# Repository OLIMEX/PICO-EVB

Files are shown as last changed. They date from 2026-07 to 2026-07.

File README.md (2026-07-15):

# PICO-EVB
Raspberry PICO/PICO-W evaluation board with optoisolated inputs 3.3-30VDC or 110-220VAC and Four Relays 15A/240VAC

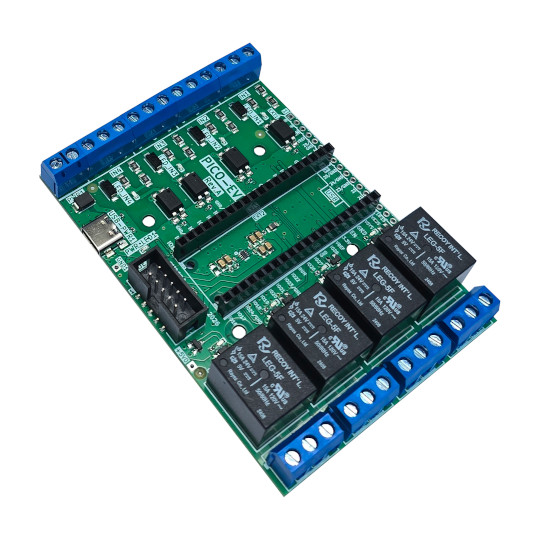
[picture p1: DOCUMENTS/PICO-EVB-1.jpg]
PICO-EVB-1


https://www.olimex.com/Products/RaspberryPi/PICO/PICO-EVB/

## Licensee
* Hardware is released under CERN Open Hardware Licence Version 2 - Strongly Reciprocal
* Software is released under MIT Licensee
* Documentation is released under CC BY-SA 4.0

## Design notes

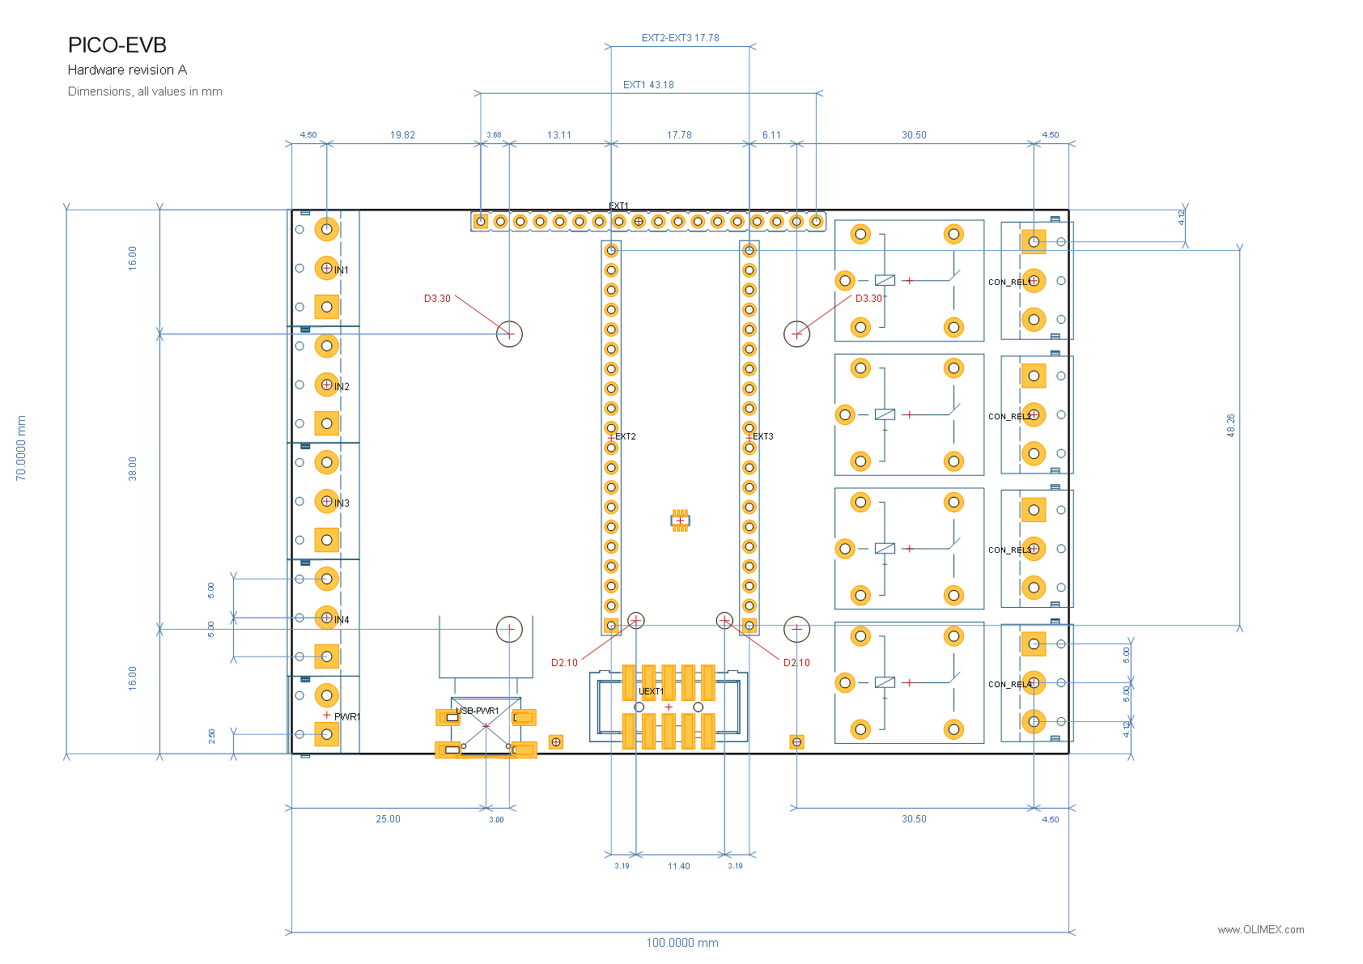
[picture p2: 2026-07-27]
DOCUMENTS/PICO-EVB-dimensions.png

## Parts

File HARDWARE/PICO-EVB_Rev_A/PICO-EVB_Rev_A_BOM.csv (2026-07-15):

Quantity | Value | Footprint | Reference
6 | 47uF/6.3V/20%/X5R/C0805 | C_0805_5MIL_DWS | C2, C3, C6, C8, C9, C10
3 | 100nF/10V/20%/X5R/C0402 | C_0402_5MIL_DWS | C4, C5, C7
8 | DG306-5.0-3P | TB3-DG306-5.0_3P | CON_REL1, CON_REL2, CON_REL3, CON_REL4, IN1, IN2, IN3, IN4
4 | 1N4148W(SOD-123) | SOD-123_1C-2A_KA | D1, D2, D7, D8
4 | 1N4007/SMA | SMA-KA | D3, D4, D5, D6
1 | SMBJ6.0A | DO214AA_1(K)-2(A) | D9
2 | PN1x20 | PN1x20 | EXT2, EXT3
1 | FB0805/600R/2A | L_0805_5MIL_DWS | L1
4 | LED/GREEN/0603 | LED_0603_KA | LED1, LED2, LED3, LED4
5 | LED/RED/0603 | LED_0603_KA | LED_IN1, LED_IN2, LED_IN3, LED_IN4, PWR_LED1
4 | PC817CS_CYPC817(C-TP2) | H11A817C_SMD(PC817X3NIP06)_FP | OPT1, OPT2, OPT3, OPT4
1 | DG306-5.0-2P | TB2-DG306-5.0_2P | PWR1
8 | 150k/R1206 | R_1206_5MIL_DWS | R1, R3, R5, R7, R11, R12, R13, R14
4 | 3.9k/R1206 | R_1206_5MIL_DWS | R2, R4, R6, R8
7 | 2.2k/R0402 | R_0402_5MIL_DWS | R9, R10, R17, R18, R23, R26, R27
1 | 24.9k/1%/R0402 | R_0402_5MIL_DWS | R15
1 | 6.81k/1%/R0402 | R_0402_5MIL_DWS | R16
4 | 47k/R0402 | R_0402_5MIL_DWS | R19, R20, R21, R22
2 | 5.1k/1%/R0402 | R_0402_5MIL_DWS | R24, R25
4 | RAS-0515 | Relay_RAS-05-15 | REL1, REL2, REL3, REL4
4 | LMUN2235LT1G(SOT-23) | SOT23 | T1, T2, T3, T4
1 | TPS2116 | SOT-5X3 | U1
1 | P-B-V-10-LF | GBH-254-SMT-10 | UEXT1
1 | USB-C-16P-F(A40-00119-A52-12) | USB2.0_TYPE-C(A40-00119-A52-12)_Paste | USB-PWR1

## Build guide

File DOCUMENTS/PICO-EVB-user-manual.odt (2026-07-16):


PICO-EVB

User Manual

Rev.1.0 July 2026 olimex.com

# Introduction to PICO-EVB

PICO-EVB (https://www.olimex.com/Products/RaspberryPi/PICO/PICO-EVB/) is evaluation board which can be used with Raspberry Pi PICO, PICO-W, PICO2 and PICO2-W. It also can work with Olimex RP2040-PICO30.

PICO-EVB (https://www.olimex.com/Products/RaspberryPi/PICO/PICO-EVB/) turns PICO into PLC and home automation device as it can drive high voltage loads with relays, and can sense via optoisolated inputs 3.3-30VDC or directly 110-220VAC signals.

PICO-EVB (https://www.olimex.com/Products/RaspberryPi/PICO/PICO-EVB/) have this features:

- 40 pin DIL connector for PICO modules
- USB-C power supply connector which allow more current to be used by the board
- Four 15A/240VAC relays controlled by the PICO
- UEXT connector
- Four opto-isolated inputs which can work either with 3.3-30VDC or 110-220VAC
- Power supply can be feed to screw connector terminal for more robust connection
- All components are industrial grade -45+85C
- Dimensions 100x70 mm

+ Important notice: The Relays and high voltage inputs should be used with care.

Each input have three connections: one common, one for +3.3-30VDC signals and one for 110/220VAC signals. If you want to drive the inputs with microcontroller feed 0 and +3.3V. If you want to drive the input with high voltage use live and neutral to connect. DO NOT CONNECT low voltage and high voltage to SAME input at the same time!

## Order codes for PICO-EVB and accessories:

PICO-EVB (https://www.olimex.com/Products/RaspberryPi/PICO/PICO-EVB/) industrial grade PICO evaluation board

USB-CABLE-A-TO-C-1M (https://www.olimex.com/Products/Components/Cables/USB/USB-CABLE-A-TO-C-1M/) USB-C quality cable for data and power

RP2040-PICO-HDR (https://www.olimex.com/Products/RaspberryPi/PICO/RP2040-PICO-HDR/) PICO with soldered headers

RP2040-PICO-W-HDR (https://www.olimex.com/Products/RaspberryPi/PICO/RP2040-PICO-W-HDR/) PICO-W with soldered headers

RP2350-PICO2-HDR (https://www.olimex.com/Products/RaspberryPi/PICO/RP2350-PICO2-HDR/) PICO2 with soldered headers

RP2350-PICO2-W-HDR (https://www.olimex.com/Products/RaspberryPi/PICO/RP2350-PICO2-W-HDR/) PICO2-W with soldered headers

# HARDWARE

## PICO-EVB layout:

PICO

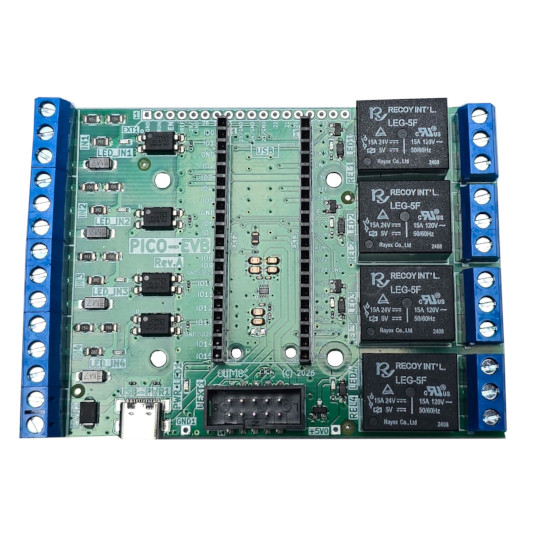
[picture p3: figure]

RELAY1

RELAY2

RELAY3

RELAY4

UEXT

GPIO connector

Input1

Input2

Input3

Input4

+5V PWR

USB-C

Relay staus LED

Power LED

Input status LED

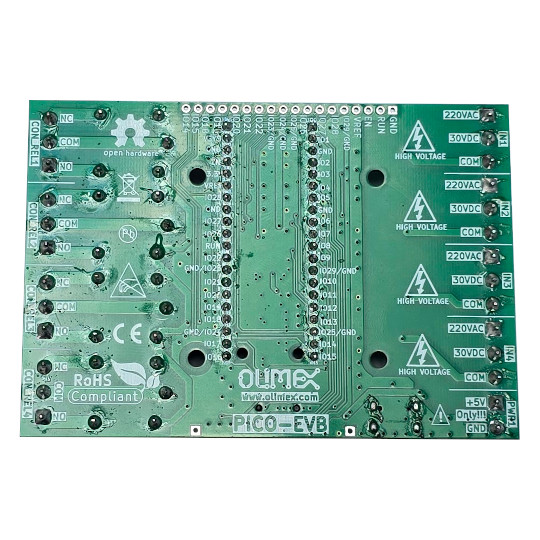
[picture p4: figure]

## PICO-EVB inputs:

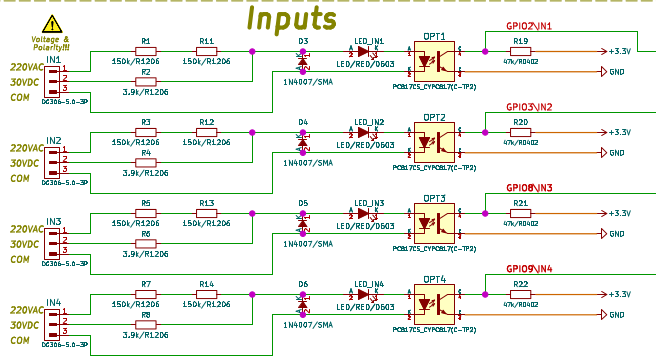
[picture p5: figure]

## PICO-EVB Relays:

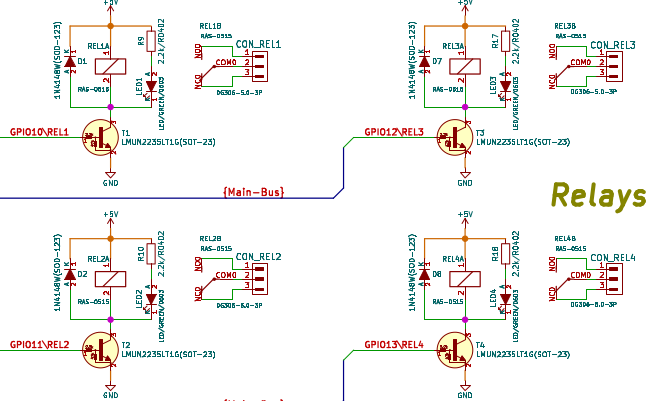
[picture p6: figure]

POWER SUPPLY:

PICO-EVB (https://www.olimex.com/Products/RaspberryPi/PICO/PICO-EVB/) can be powered by: USB-C connector, Terminal Block connector, PICO USB connector

You can connect any of them or all at the same time and it will be safe.

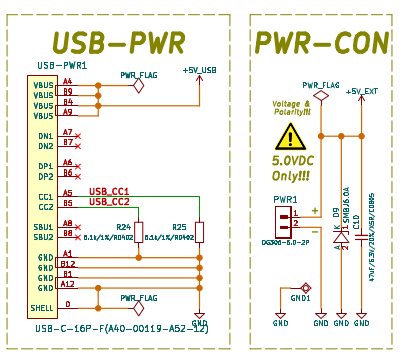
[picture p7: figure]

There is priority circuit if you connect together USB-C and Termianl block external power, the priority will be USB-C.

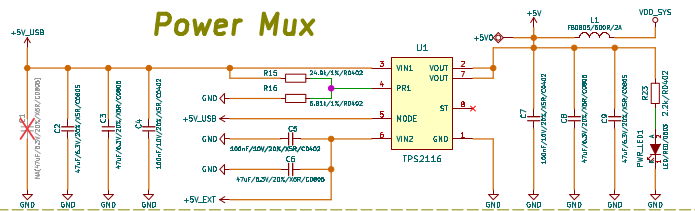
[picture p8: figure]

## PICO-EVB schematics:

PICO-EVB (https://www.olimex.com/Products/RaspberryPi/PICO/PICO-EVB/) latest schematic is on GitHub (https://github.com/OLIMEX/PICO-EVB)

## UEXT connector:

UEXT connector stands for Universal EXTension connector and contain +3.3V, GND, I2C, SPI, UART signals.

UEXT connector can be in different shapes.

The original UEXT connector is 0.1” 2.54mm step boxed plastic connector. All signals are with 3.3V levels.

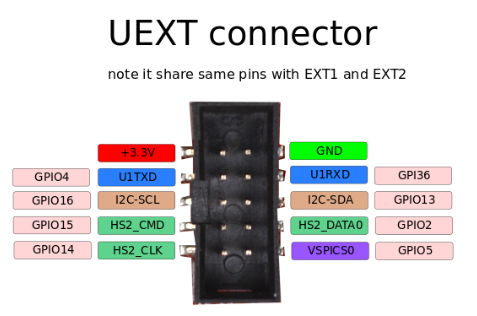
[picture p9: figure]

As the boards become smaller and smaller some smaller packages were introduced too beside the original UEXT connector

- mUEXT is 1.27 mm step boxed header connector which is with same layout as UEXT

- pUEXT is 1.0 mm single row connector (this is the connector used in RP2040-PICO30)

Olimex has developed number of MODULES (https://www.olimex.com/Products/Modules/) with this connector. There are temperature, humidity, pressure, magnetic field, light sensors. Modules with LCDs, LED matrix, Relays, Bluetooth, Zigbee, WiFi, GSM, GPS, RFID, RTC, EKG, sensors and etc.

# SOFTWARE:

PICO-EVB (https://www.olimex.com/Products/RaspberryPi/PICO/PICO-EVB/) repository have these software:

- Arduino-demo (https://github.com/OLIMEX/PICO-EVB/tree/main/SOFTWARE/Arduino-demo)
- ESPHome (https://github.com/OLIMEX/PICO-EVB/tree/main/SOFTWARE/ESPHome)
- MicroPython-demo (https://github.com/OLIMEX/PICO-EVB/tree/main/SOFTWARE/MicroPython-demo)
- MicroPython-server (https://github.com/OLIMEX/PICO-EVB/tree/main/SOFTWARE/MicroPython-server)

# Revision History

Revision 1.0 July 2026

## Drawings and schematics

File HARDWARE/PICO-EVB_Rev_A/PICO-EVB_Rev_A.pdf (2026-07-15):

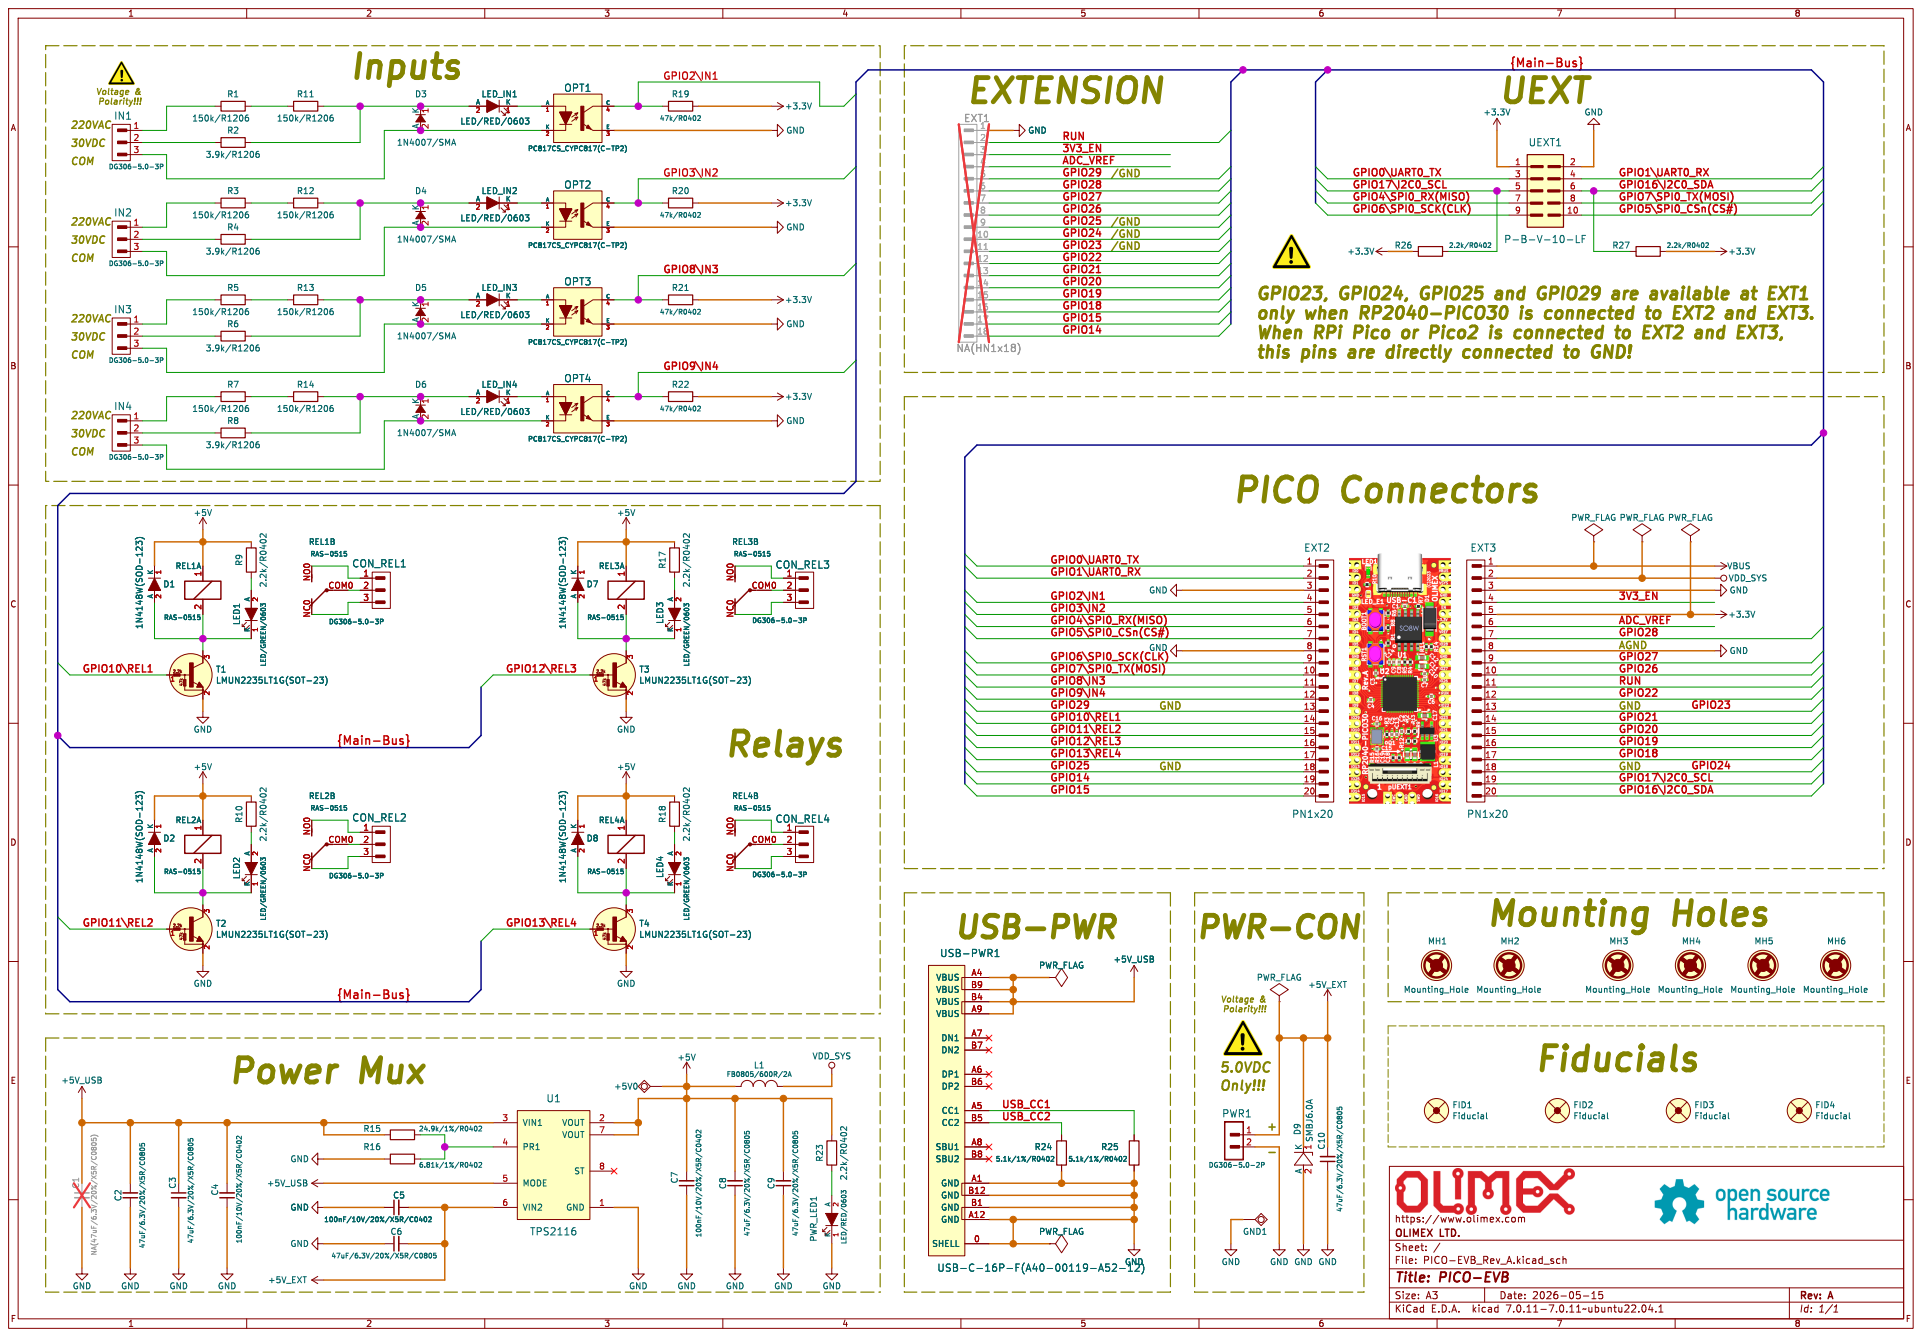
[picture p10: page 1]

When RPi Pico or Pico2 is connected to EXT2 and EXT3,
this pins are directly connected to GND!

File: PICO-EVB_Rev_A.kicad_sch Sheet: / OLIMEX LTD. https://www.olimex.com

Id: 1/1 Title: PICO-EVB

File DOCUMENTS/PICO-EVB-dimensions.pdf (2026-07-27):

# PICO-EVB

## Hardware revision A

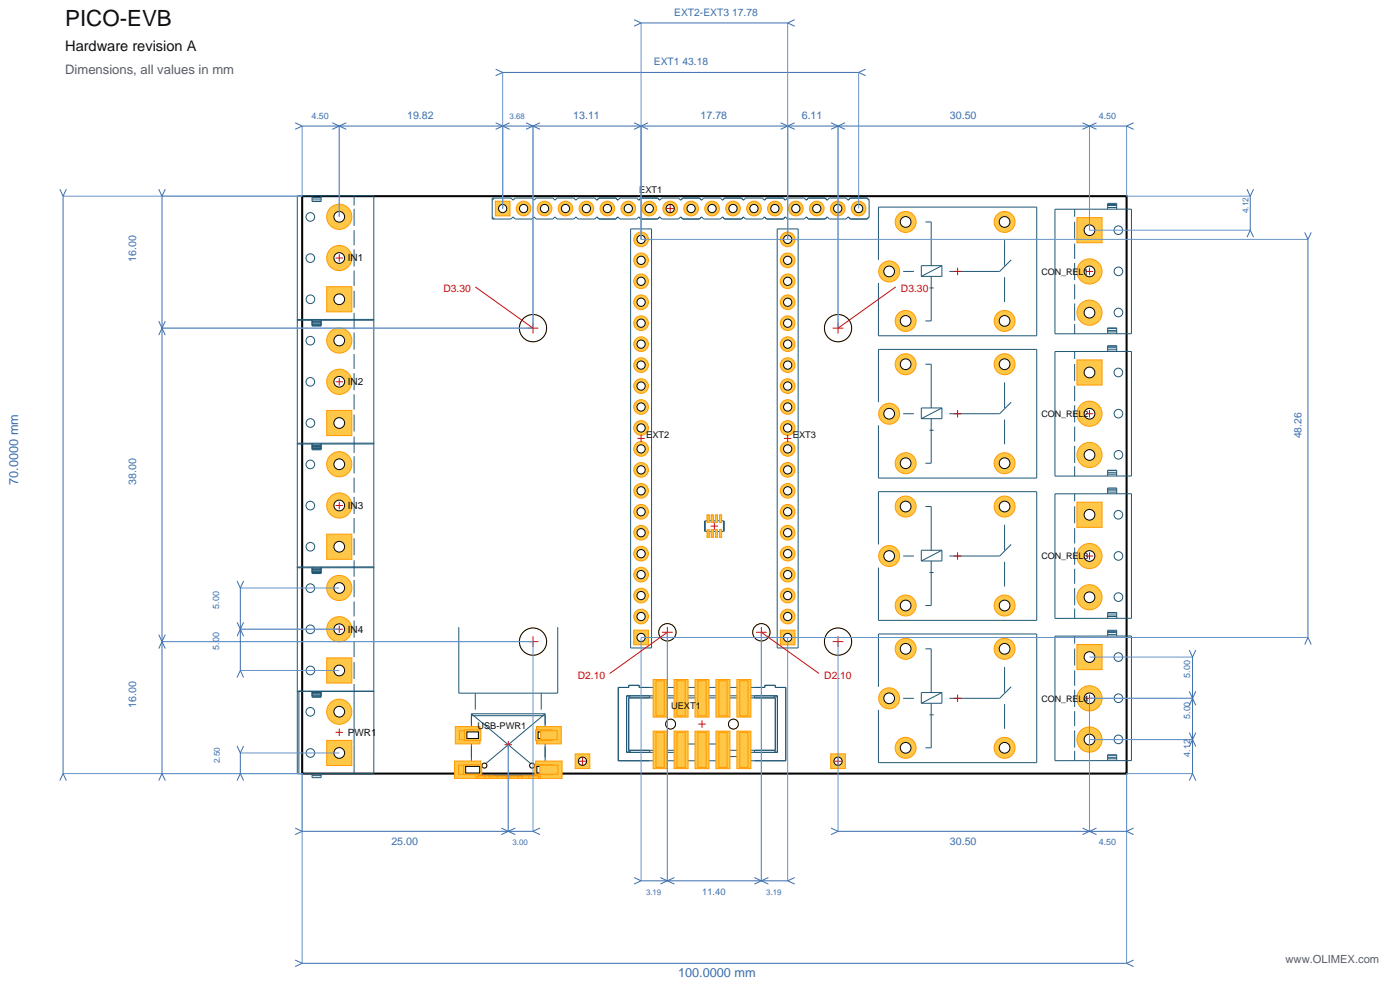
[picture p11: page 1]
CON_REL2; CON_REL4; EXT2; EXT1; UEXT1; CON_REL1; USB-PWR1 PWR1; EXT3; CON_REL3; EXT1 43.18; EXT2-EXT3 17.78

Dimensions, all values in mm

www.OLIMEX.com

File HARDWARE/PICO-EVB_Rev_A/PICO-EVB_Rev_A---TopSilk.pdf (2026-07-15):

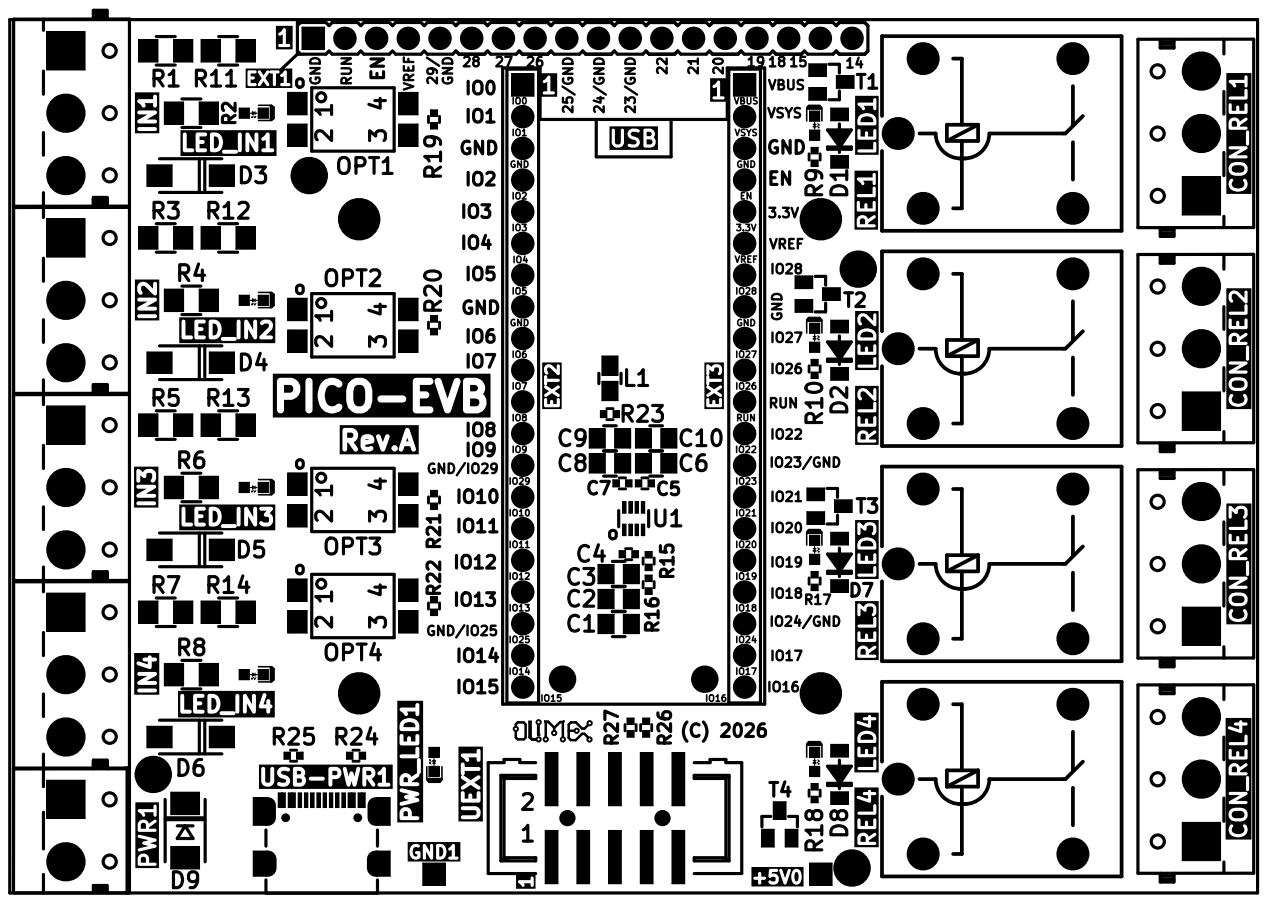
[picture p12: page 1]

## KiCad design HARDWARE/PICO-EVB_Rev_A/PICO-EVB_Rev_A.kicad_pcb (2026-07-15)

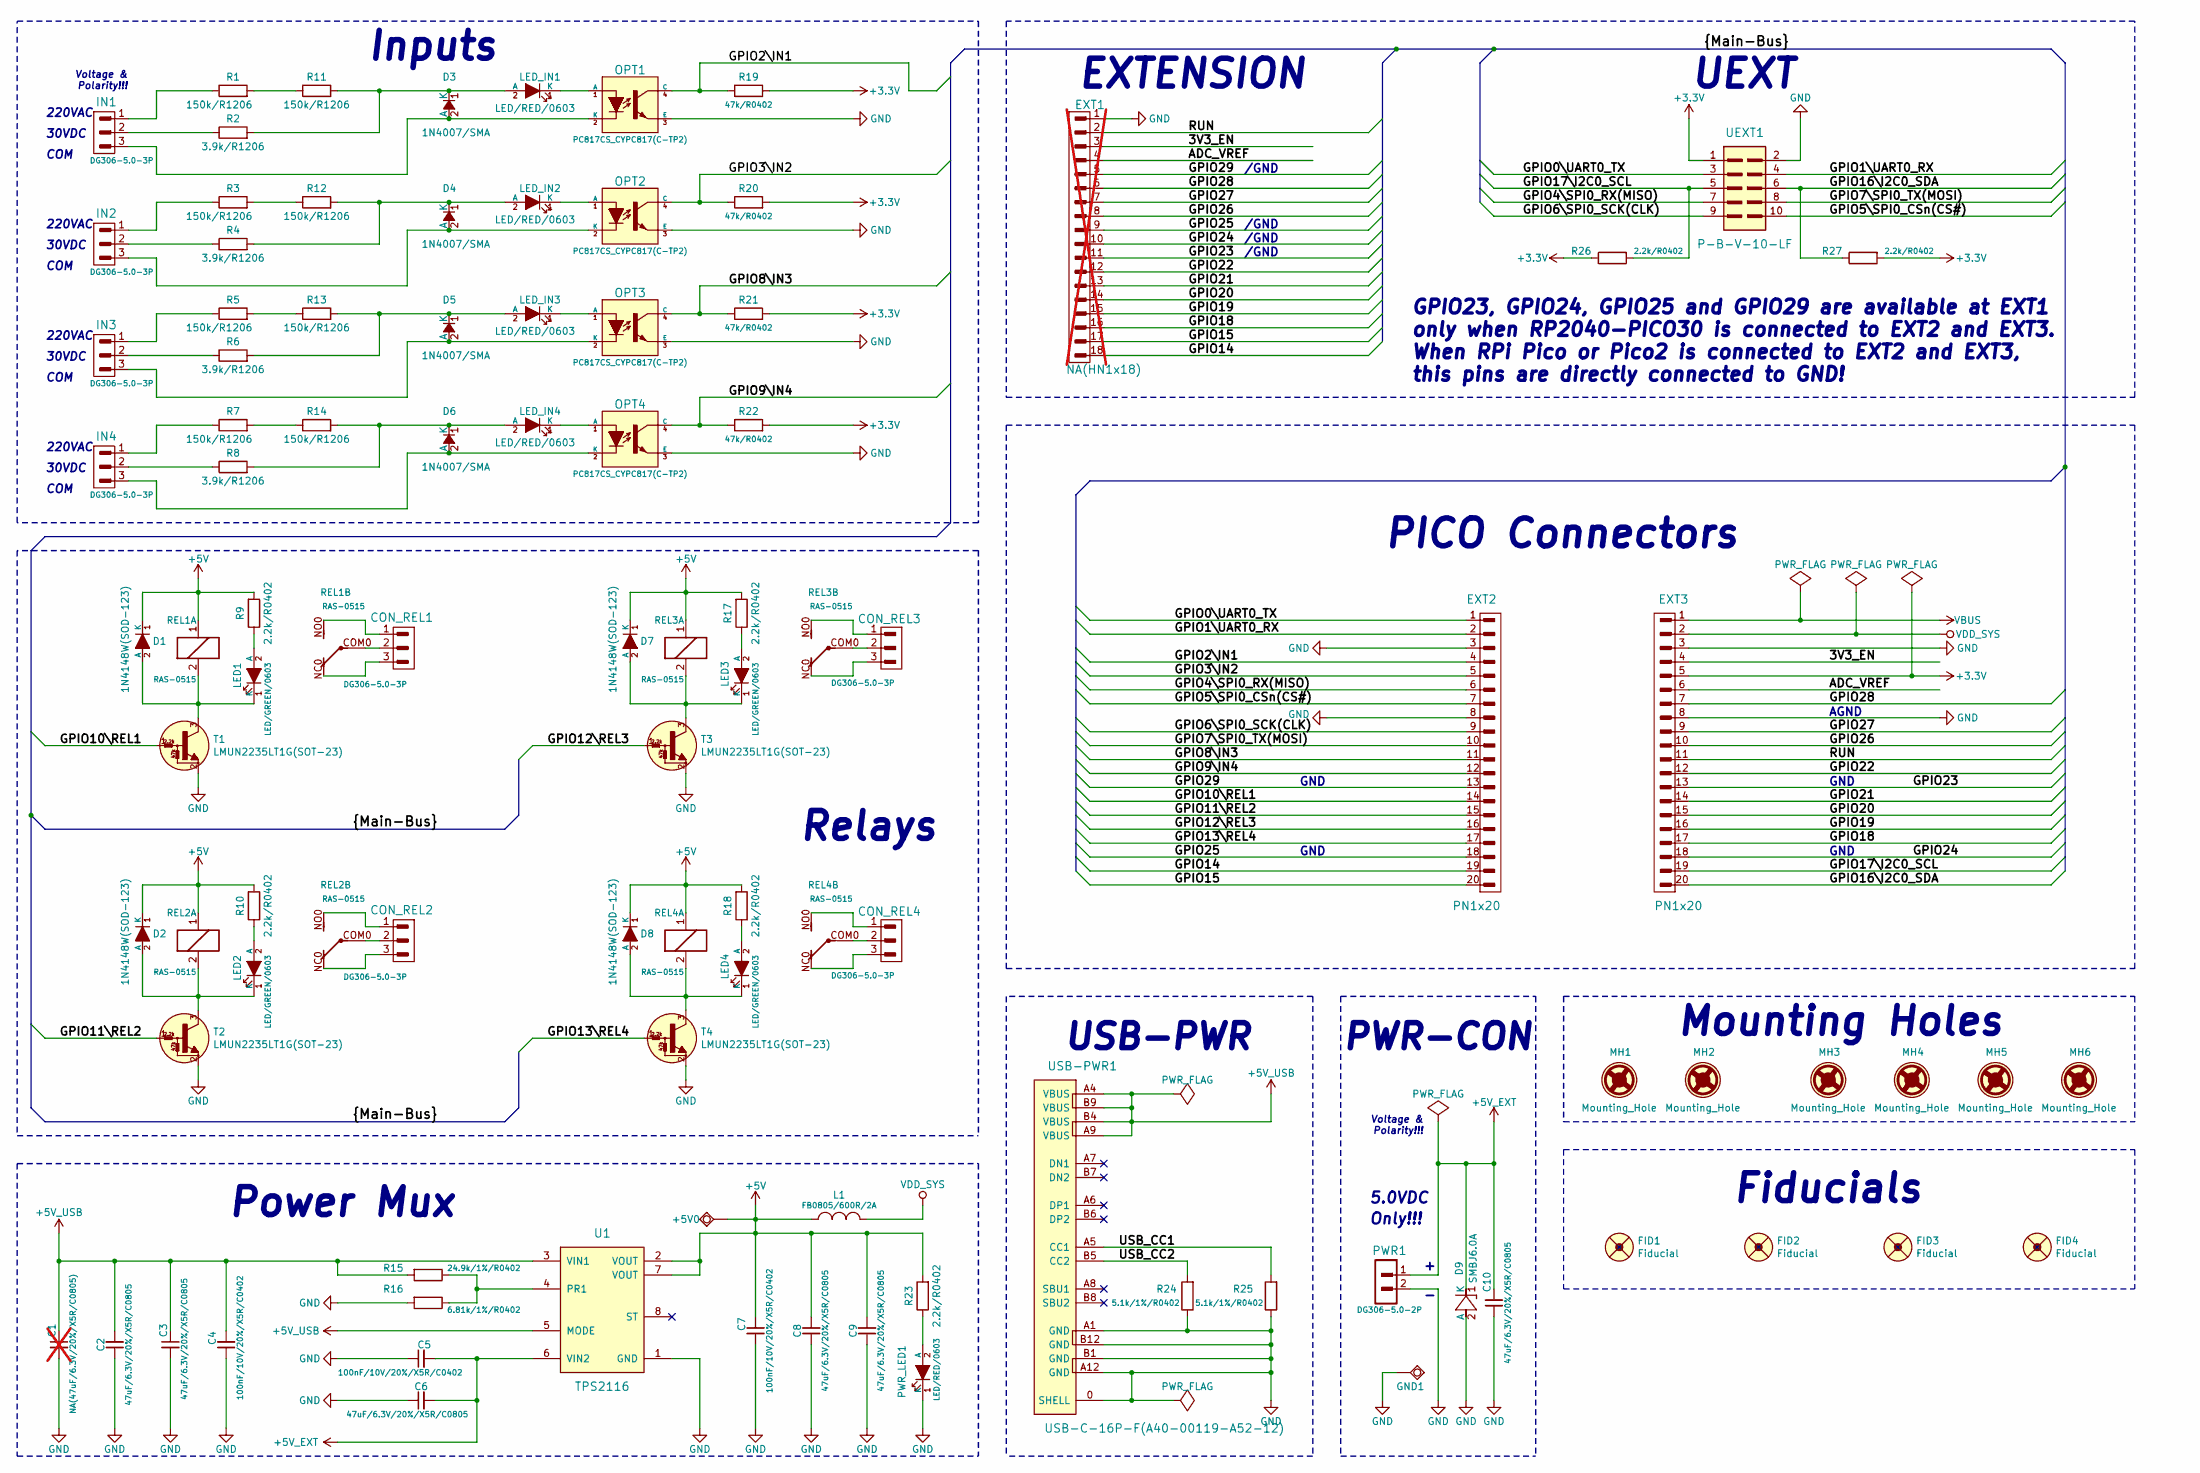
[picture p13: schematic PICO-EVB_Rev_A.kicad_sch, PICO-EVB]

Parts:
+5V0: TESTPAD; TEST_PAD40x70_SQUARE
C1: NA(47uF/6.3V/20%/X5R/C0805); C_0805_5MIL_DWS; not fitted
C2, C3, C6, C8, C9, C10: 47uF/6.3V/20%/X5R/C0805; C_0805_5MIL_DWS
C4, C5, C7: 100nF/10V/20%/X5R/C0402; C_0402_5MIL_DWS
CON_REL1, CON_REL2, CON_REL3, CON_REL4: DG306-5.0-3P; TB3-DG306-5.0_3P
D1, D2, D7, D8: 1N4148W(SOD-123); SOD-123_1C-2A_KA
D3, D4, D5, D6: 1N4007/SMA; SMA-KA
D9: SMBJ6.0A; DO214AA_1(K)-2(A)
EXT1: NA(HN1x18); HN1x18; not fitted
EXT2, EXT3: PN1x20
FID1, FID3: Fiducial; Fiducial1x3
FID2, FID4: Fiducial; Fiducial1x3_Paste
GND1: TESTPAD; TEST_PAD40x70_SQUARE
IN1, IN2, IN3, IN4: DG306-5.0-3P; TB3-DG306-5.0_3P
L1: FB0805/600R/2A; L_0805_5MIL_DWS
LED1, LED2, LED3, LED4: LED/GREEN/0603; LED_0603_KA
LED_IN1, LED_IN2, LED_IN3, LED_IN4: LED/RED/0603; LED_0603_KA
MH1, MH2: Mounting_Hole; Mounting_Hole_Drill-2.1mm_Clerance-4mm
MH3, MH4, MH5, MH6: Mounting_Hole; Mounting_Hole_Drill-3.3mm_Clerance-7mm
OPT1, OPT2, OPT3, OPT4: PC817CS_CYPC817(C-TP2); H11A817C_SMD(PC817X3NIP06)_FP
PWR1: DG306-5.0-2P; TB2-DG306-5.0_2P
PWR_LED1: LED/RED/0603; LED_0603_KA
R1, R3, R5, R7, R11, R12, R13, R14: 150k/R1206; R_1206_5MIL_DWS
R2, R4, R6, R8: 3.9k/R1206; R_1206_5MIL_DWS
R9, R10, R17, R18, R23, R26, R27: 2.2k/R0402; R_0402_5MIL_DWS
R15: 24.9k/1%/R0402; R_0402_5MIL_DWS
R16: 6.81k/1%/R0402; R_0402_5MIL_DWS
R19, R20, R21, R22: 47k/R0402; R_0402_5MIL_DWS
R24, R25: 5.1k/1%/R0402; R_0402_5MIL_DWS
REL1, REL2, REL3, REL4: RAS-0515; Relay_RAS-05-15
T1, T2, T3, T4: LMUN2235LT1G(SOT-23); SOT23
U1: TPS2116; SOT-5X3
UEXT1: P-B-V-10-LF; GBH-254-SMT-10
USB-PWR1: USB-C-16P-F(A40-00119-A52-12); USB2.0_TYPE-C(A40-00119-A52-12)_Paste

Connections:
+3.3V: EXT3.5, R19.2, R20.2, R21.2, R22.2, R26.1, R27.2, UEXT1.1
+5V: +5V0.1 (Pad), C7.2, C8.2, C9.2, D1.1 (K), D2.1 (K), D7.1 (K), D8.1 (K), L1.1, R9.2, R10.2, R17.2, R18.2, R23.2, REL1.1, REL2.1, REL3.1, REL4.1, U1.2 (VOUT), U1.7 (VOUT)
+5V_EXT: C5.2, C6.2, C10.2, D9.1 (K), PWR1.1, U1.6 (VIN2)
+5V_USB: C1.1, C2.2, C3.1, C4.2, R15.2, U1.3 (VIN1), U1.5 (MODE), USB-PWR1.A4 (VBUS), USB-PWR1.A9 (VBUS), USB-PWR1.B4 (VBUS), USB-PWR1.B9 (VBUS)
/3V3_EN: EXT1.3, EXT3.4
/ADC_VREF: EXT1.4, EXT3.6
/GPIO0\UART0_TX: EXT2.1, UEXT1.3
/GPIO1\UART0_RX: EXT2.2, UEXT1.4
/GPIO2\IN1: EXT2.4, OPT1.4 (C), R19.1
/GPIO3\IN2: EXT2.5, OPT2.4 (C), R20.1
/GPIO4\SPI0_RX(MISO): EXT2.6, UEXT1.7
/GPIO5\SPI0_CSn(CS#): EXT2.7, UEXT1.10
/GPIO6\SPI0_SCK(CLK): EXT2.9, UEXT1.9
/GPIO7\SPI0_TX(MOSI): EXT2.10, UEXT1.8
/GPIO8\IN3: EXT2.11, OPT3.4 (C), R21.1
/GPIO9\IN4: EXT2.12, OPT4.4 (C), R22.1
/GPIO10\REL1: EXT2.14, T1.1 (B)
/GPIO11\REL2: EXT2.15, T2.1 (B)
/GPIO12\REL3: EXT2.16, T3.1 (B)
/GPIO13\REL4: EXT2.17, T4.1 (B)
/GPIO14: EXT1.18, EXT2.19
/GPIO15: EXT1.17, EXT2.20
/GPIO16\I2C0_SDA: EXT3.20, R27.1, UEXT1.6
/GPIO17\I2C0_SCL: EXT3.19, R26.2, UEXT1.5
/GPIO18: EXT1.16, EXT3.17
/GPIO19: EXT1.15, EXT3.16
/GPIO20: EXT1.14, EXT3.15
/GPIO21: EXT1.13, EXT3.14
/GPIO22: EXT1.12, EXT3.12
/GPIO23: EXT1.11, EXT3.13
/GPIO24: EXT1.10, EXT3.18
/GPIO25: EXT1.9, EXT2.18
/GPIO26: EXT1.8, EXT3.10
/GPIO27: EXT1.7, EXT3.9
/GPIO28: EXT1.6, EXT3.7
/GPIO29: EXT1.5, EXT2.13
/RUN: EXT1.2, EXT3.11
/USB_CC1: R25.2, USB-PWR1.A5 (CC1)
/USB_CC2: R24.2, USB-PWR1.B5 (CC2)
GND: C1.2, C2.1, C3.2, C4.1, C5.1, C6.1, C7.1, C8.1, C9.1, C10.1, D9.2 (A), EXT1.1, EXT2.3, EXT2.8, EXT3.3, EXT3.8, GND1.1 (Pad), OPT1.3 (E), OPT2.3 (E), OPT3.3 (E), OPT4.3 (E), PWR1.2, PWR_LED1.1 (K), R16.2, R24.1, R25.1, T1.2 (E), T2.2 (E), T3.2 (E), T4.2 (E), U1.1 (GND), UEXT1.2, USB-PWR1.0 (SHELL), USB-PWR1.A1 (GND), USB-PWR1.A12 (GND), USB-PWR1.B1 (GND), USB-PWR1.B12 (GND)
unnamed: CON_REL1.1, REL1.NO0
unnamed: CON_REL1.2, REL1.COM0
unnamed: CON_REL1.3, REL1.NC0
unnamed: CON_REL2.1, REL2.NO0
unnamed: CON_REL2.2, REL2.COM0
unnamed: CON_REL2.3, REL2.NC0
unnamed: CON_REL3.1, REL3.NO0
unnamed: CON_REL3.2, REL3.COM0
unnamed: CON_REL3.3, REL3.NC0
unnamed: CON_REL4.1, REL4.NO0
unnamed: CON_REL4.2, REL4.COM0
unnamed: CON_REL4.3, REL4.NC0
unnamed: D1.2 (A), LED1.1 (K), REL1.2, T1.3 (C)
unnamed: D2.2 (A), LED2.1 (K), REL2.2, T2.3 (C)
unnamed: D3.2 (A), IN1.3, OPT1.2 (K)
unnamed: D3.1 (K), LED_IN1.2 (A), R2.2, R11.2
unnamed: D4.2 (A), IN2.3, OPT2.2 (K)
unnamed: D4.1 (K), LED_IN2.2 (A), R4.2, R12.2
unnamed: D5.2 (A), IN3.3, OPT3.2 (K)
unnamed: D5.1 (K), LED_IN3.2 (A), R6.2, R13.2
unnamed: D6.2 (A), IN4.3, OPT4.2 (K)
unnamed: D6.1 (K), LED_IN4.2 (A), R8.2, R14.2
unnamed: D7.2 (A), LED3.1 (K), REL3.2, T3.3 (C)
unnamed: D8.2 (A), LED4.1 (K), REL4.2, T4.3 (C)
unnamed: IN1.1, R1.1
unnamed: IN1.2, R2.1
unnamed: IN2.1, R3.1
unnamed: IN2.2, R4.1
unnamed: IN3.1, R5.1
unnamed: IN3.2, R6.1
unnamed: IN4.1, R7.1
unnamed: IN4.2, R8.1
unnamed: LED1.2 (A), R9.1
unnamed: LED2.2 (A), R10.1
unnamed: LED3.2 (A), R17.1
unnamed: LED4.2 (A), R18.1
unnamed: LED_IN1.1 (K), OPT1.1 (A)
unnamed: LED_IN2.1 (K), OPT2.1 (A)
unnamed: LED_IN3.1 (K), OPT3.1 (A)
unnamed: LED_IN4.1 (K), OPT4.1 (A)
unnamed: PWR_LED1.2 (A), R23.1
unnamed: R1.2, R11.1
unnamed: R3.2, R12.1
unnamed: R5.2, R13.1
unnamed: R7.2, R14.1
unnamed: R15.1, R16.1, U1.4 (PR1)
VBUS: EXT3.1
VDD_SYS: EXT3.2, L1.2

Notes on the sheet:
30VDC
PWR-CON
220VAC
/GND
AGND
Mounting Holes
USB-PWR
Fiducials
COM
Voltage & Polarity!!!
EXTENSION
GPIO23, GPIO24, GPIO25 and GPIO29 are available at EXT1 only when RP2040-PICO30 is connected to EXT2 and EXT3. When RPi Pico or Pico2 is connected to EXT2 and EXT3, this pins are directly connected to GND!
5.0VDC
Relays
Power Mux
UEXT
GND
Inputs
PICO Connectors
Only!!!

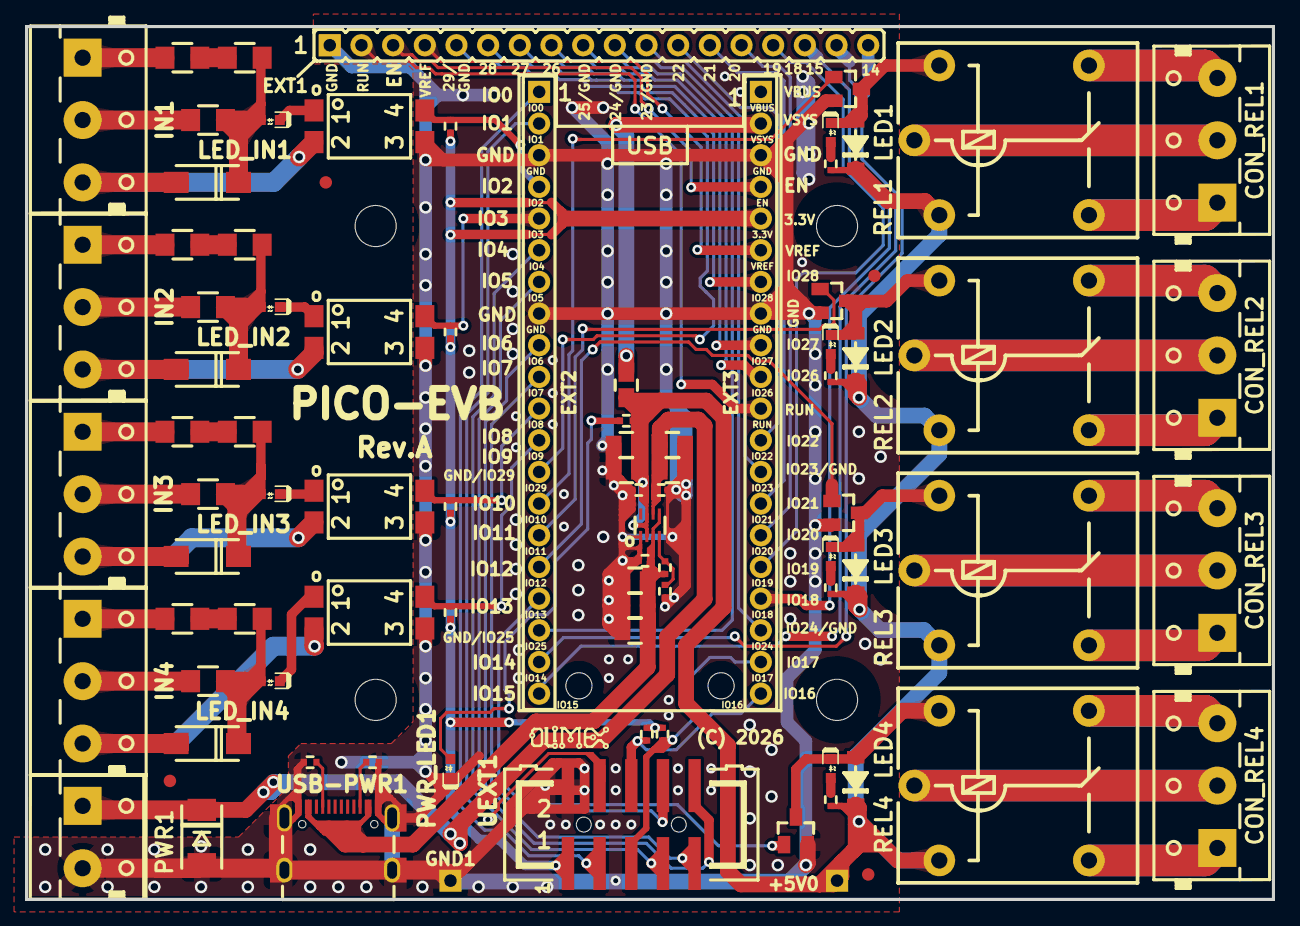
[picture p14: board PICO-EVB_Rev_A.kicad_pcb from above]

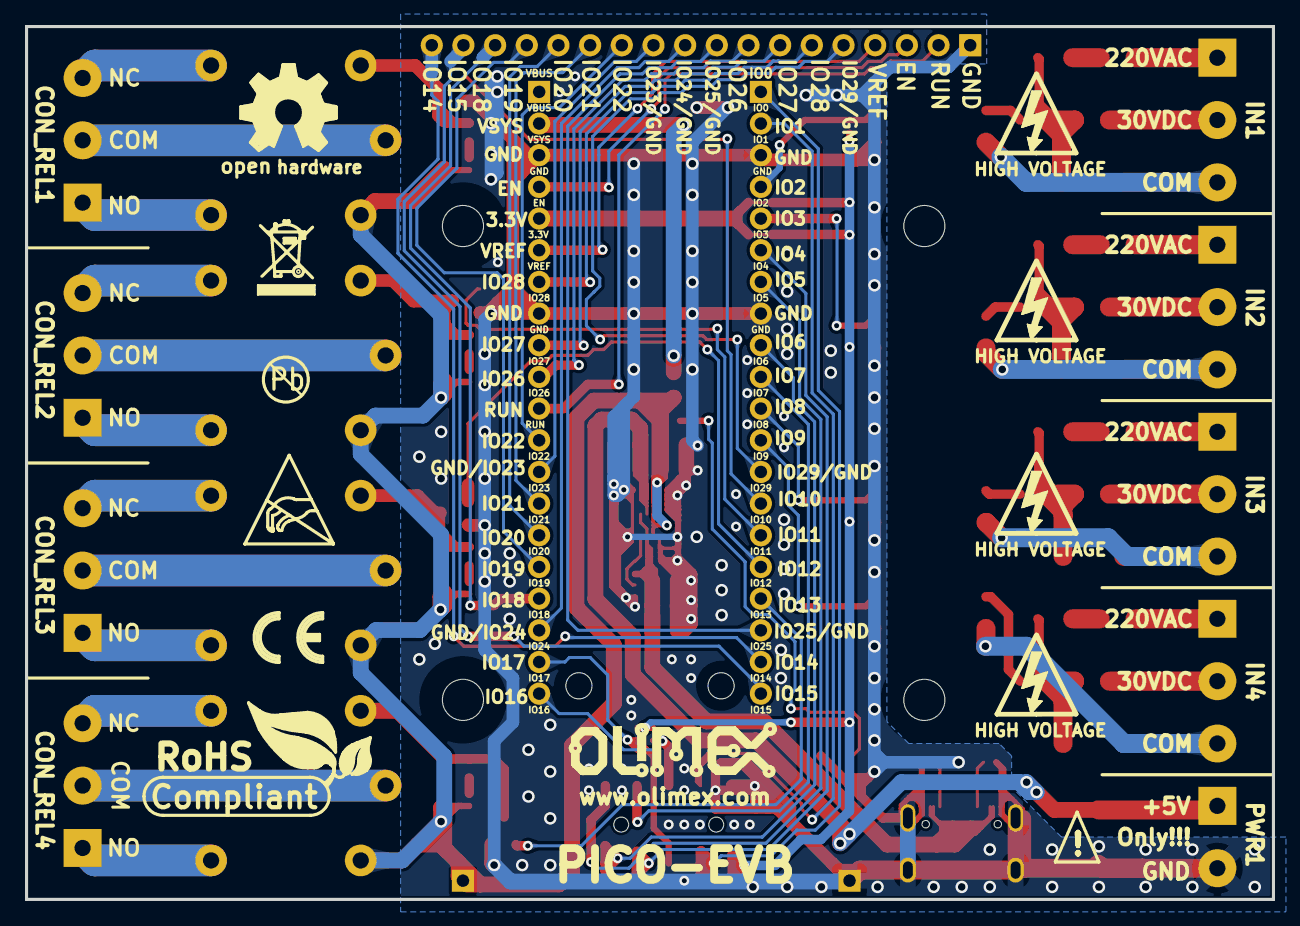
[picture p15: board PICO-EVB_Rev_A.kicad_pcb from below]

Board: 2 copper layers, 100.0 x 70.0 mm, 107 parts (11 on the bottom side), 87 nets.

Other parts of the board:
Logo_OLIMEX_SMALL_TB: Logo_OLIMEX_SMALL_TB
Logo_OLIMEX_TB: Logo_OLIMEX_TB
Sign_Antistatic: Sign_Antistatic
Sign_CE: CE_Sign
Sign_High_Voltage: Sign_High_Voltage
Sign_High_Voltage#2, Sign_High_Voltage#3, Sign_High_Voltage#4: Sign_High_Voltage
Sign_OSHW_8x8: Sign_OSHW_8x8
Sign_PB-Free: Sign_PB-Free
Sign_RecycleBin_1: Sign_RecycleBin_1
Sign_RoHS_1: Sign_RoHS_1

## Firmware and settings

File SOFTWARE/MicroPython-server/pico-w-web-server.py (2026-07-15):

"""
MicroPython firmware for Raspberry Pi Pico W
- 4 digital inputs (debounced: 0 for >=5ms => ON, 1 for >=60ms => OFF), 4 relay outputs
- UART / I2C / SPI pins reserved (initialized, not otherwise used)
- Simple web server: shows input state as ON/OFF icons, buttons toggle relays
- Relays are forced OFF on boot and on any unhandled error

Pin map (per request):
  GPIO2  - Input1
  GPIO3  - Input2
  GPIO8  - Input3
  GPIO9  - Input4
  GPIO10 - RELAY1
  GPIO11 - RELAY2
  GPIO12 - RELAY3
  GPIO13 - RELAY4
  GPIO0  - UART0 TX
  GPIO1  - UART0 RX
  GPIO16 - I2C0 SDA
  GPIO17 - I2C0 SCL
  GPIO4  - SPI0 MISO (RX)
  GPIO5  - SPI0 CS
  GPIO6  - SPI0 SCK
  GPIO7  - SPI0 MOSI (TX)
"""

import network
import socket
import time
import machine
from machine import Pin, UART, I2C, SPI

# ---------------------------------------------------------------------------
# Wi-Fi credentials - EDIT THESE
# ---------------------------------------------------------------------------
WIFI_SSID = "yourSSID"
WIFI_PASSWORD = "yourPASSWORD"

# ---------------------------------------------------------------------------
# I/O setup
# ---------------------------------------------------------------------------

# Inputs. Change PULL_UP/PULL_DOWN to match your wiring (e.g. switch to GND
# needs PULL_UP, switch to 3V3 needs PULL_DOWN).
inputs = [
    Pin(2, Pin.IN, Pin.PULL_UP),
    Pin(3, Pin.IN, Pin.PULL_UP),
    Pin(8, Pin.IN, Pin.PULL_UP),
    Pin(9, Pin.IN, Pin.PULL_UP),
]

# ---------------------------------------------------------------------------
# Input debounce
#   raw = 0 held for >= DEBOUNCE_ON_MS  -> considered ON
#   raw = 1 held for >= DEBOUNCE_OFF_MS -> considered OFF
# Sampled from a periodic timer so it works independently of HTTP requests.
# ---------------------------------------------------------------------------
DEBOUNCE_ON_MS = 5
DEBOUNCE_OFF_MS = 60

_num_inputs = len(inputs)
_last_raw = [p.value() for p in inputs]
_last_change_ms = [time.ticks_ms()] * _num_inputs
debounced_state = [0 if v else 1 for v in _last_raw]  # raw 1 (idle) -> OFF(0)


def _debounce_tick(timer):
    now = time.ticks_ms()
    for i in range(_num_inputs):
        raw = inputs[i].value()
        if raw != _last_raw[i]:
            _last_raw[i] = raw
            _last_change_ms[i] = now
        else:
            elapsed = time.ticks_diff(now, _last_change_ms[i])
            if raw == 0 and elapsed >= DEBOUNCE_ON_MS:
                debounced_state[i] = 1
            elif raw == 1 and elapsed >= DEBOUNCE_OFF_MS:
                debounced_state[i] = 0


debounce_timer = machine.Timer(-1)
debounce_timer.init(period=1, mode=machine.Timer.PERIODIC, callback=_debounce_tick)

# Relays - active HIGH (change if your relay board is active LOW)
relays = [
    Pin(10, Pin.OUT),
    Pin(11, Pin.OUT),
    Pin(12, Pin.OUT),
    Pin(13, Pin.OUT),
]


def relays_off():
    """Force all relays to the OFF state."""
    for r in relays:
        r.value(0)


# Make sure relays start OFF
relays_off()

# Reserved peripherals (initialized so pins are claimed / configured, not
# otherwise used by the web server logic below)
uart = UART(0, baudrate=115200, tx=Pin(0), rx=Pin(1))
i2c = I2C(0, sda=Pin(16), scl=Pin(17), freq=400000)
spi = SPI(0, baudrate=1_000_000, sck=Pin(6), mosi=Pin(7), miso=Pin(4))
spi_cs = Pin(5, Pin.OUT, value=1)  # CS idle HIGH


# ---------------------------------------------------------------------------
# Wi-Fi connect
# ---------------------------------------------------------------------------
def wifi_connect(timeout_s=20):
    wlan = network.WLAN(network.STA_IF)
    wlan.active(True)
    wlan.connect(WIFI_SSID, WIFI_PASSWORD)

    t0 = time.time()
    while not wlan.isconnected():
        if time.time() - t0 > timeout_s:
            raise RuntimeError("Wi-Fi connection timed out")
        time.sleep(0.5)

    print("Connected, IP:", wlan.ifconfig()[0])
    return wlan


# ---------------------------------------------------------------------------
# Web page
# ---------------------------------------------------------------------------
PAGE = """<!DOCTYPE html>
<html>
<head>
<meta charset="utf-8">
<meta name="viewport" content="width=device-width, initial-scale=1">
<title>Pico W I/O Panel</title>
<style>
  body { font-family: Arial, sans-serif; background:#1e1e1e; color:#eee;
         text-align:center; margin:0; padding:20px; }
  h1 { font-size:1.4em; }
  .grid { display:flex; justify-content:center; gap:24px; flex-wrap:wrap; margin:20px 0; }
  .card { background:#2b2b2b; border-radius:12px; padding:16px; width:140px; }
  .label { font-size:0.9em; color:#bbb; margin-top:10px; }

  /* Toggle switch, styled after the red/OFF - green/ON pill icon */
  .toggle {
    display:inline-flex;
    align-items:center;
    justify-content:space-between;
    width:110px;
    height:44px;
    border-radius:22px;
    background:#292c33;
    padding:0 10px;
    box-sizing:border-box;
    border:none;
    font-family:inherit;
  }
  .toggle.clickable { cursor:pointer; }
  .toggle .txt {
    color:#fff;
    font-weight:bold;
    font-size:0.85em;
    letter-spacing:0.5px;
  }
  .toggle .knob {
    width:28px;
    height:28px;
    border-radius:50%;
    flex-shrink:0;
  }
  .toggle .knob.red   { background:#e8483a; }
  .toggle .knob.green { background:#22a75d; }
</style>
</head>
<body>
<h1>Pico W Input / Relay Panel</h1>

<h2>Inputs</h2>
<div class="grid" id="inputs"></div>

<h2>Relays</h2>
<div class="grid" id="relays"></div>

<script>
async function refresh() {
  try {
    const r = await fetch('/status.json');
    const data = await r.json();

    const inDiv = document.getElementById('inputs');
    inDiv.innerHTML = '';
    data.inputs.forEach((v, i) => {
      const active = v === 1;   // debounced_state: 1 = ON, 0 = OFF
      const switchHtml = active
        ? `<div class="toggle"><span class="txt">ON</span><span class="knob green"></span></div>`
        : `<div class="toggle"><span class="knob red"></span><span class="txt">OFF</span></div>`;
      inDiv.innerHTML += `
        <div class="card">
          ${switchHtml}
          <div class="label">Input ${i+1}</div>
        </div>`;
    });

    const relDiv = document.getElementById('relays');
    relDiv.innerHTML = '';
    data.relays.forEach((v, i) => {
      const switchHtml = v
        ? `<div class="toggle clickable" onclick="toggle(${i})"><span class="txt">ON</span><span class="knob green"></span></div>`
        : `<div class="toggle clickable" onclick="toggle(${i})"><span class="knob red"></span><span class="txt">OFF</span></div>`;
      relDiv.innerHTML += `
        <div class="card">
          ${switchHtml}
          <div class="label">Relay ${i+1}</div>
        </div>`;
    });
  } catch (e) {
    console.log('status refresh failed', e);
  }
}

async function toggle(i) {
  await fetch('/relay/' + i + '/toggle');
  refresh();
}

refresh();
setInterval(refresh, 1500);
</script>
</body>
</html>
"""


# ---------------------------------------------------------------------------
# HTTP helpers
# ---------------------------------------------------------------------------
def read_inputs():
    return list(debounced_state)


def read_relays():
    return [r.value() for r in relays]


def json_status():
    ins = read_inputs()
    rel = read_relays()
    body = '{"inputs":[%d,%d,%d,%d],"relays":[%d,%d,%d,%d]}' % (
        ins[0], ins[1], ins[2], ins[3],
        rel[0], rel[1], rel[2], rel[3],
    )
    return body


def send_response(conn, body, content_type="text/html"):
    header = (
        "HTTP/1.1 200 OK\r\n"
        "Content-Type: {}\r\n"
        "Content-Length: {}\r\n"
        "Connection: close\r\n\r\n"
    ).format(content_type, len(body))
    conn.send(header.encode())
    conn.send(body.encode() if isinstance(body, str) else body)


def send_404(conn):
    body = "Not found"
    header = (
        "HTTP/1.1 404 Not Found\r\n"
        "Content-Type: text/plain\r\n"
        "Content-Length: {}\r\n"
        "Connection: close\r\n\r\n"
    ).format(len(body))
    conn.send(header.encode())
    conn.send(body.encode())


def handle_request(conn, request):
    # First line looks like: GET /path HTTP/1.1
    try:
        first_line = request.split("\r\n", 1)[0]
        method, path, _ = first_line.split(" ")
    except Exception:
        send_404(conn)
        return

    if path == "/" or path == "/index.html":
        send_response(conn, PAGE)
        return

    if path == "/status.json":
        send_response(conn, json_status(), "application/json")
        return

    if path.startswith("/relay/") and path.endswith("/toggle"):
        try:
            idx = int(path.split("/")[2])
            if 0 <= idx < len(relays):
                relays[idx].value(0 if relays[idx].value() else 1)
                send_response(conn, json_status(), "application/json")
                return
        except Exception:
            pass
        send_404(conn)
        return

    send_404(conn)


# ---------------------------------------------------------------------------
# Server loop
# ---------------------------------------------------------------------------
def run_server():
    addr = socket.getaddrinfo("0.0.0.0", 80)[0][-1]
    s = socket.socket()
    s.setsockopt(socket.SOL_SOCKET, socket.SO_REUSEADDR, 1)
    s.bind(addr)
    s.listen(4)
    print("Web server listening on", addr)

    while True:
        conn, client_addr = s.accept()
        try:
            conn.settimeout(3.0)
            request = conn.recv(1024).decode("utf-8", "ignore")
            if request:
                handle_request(conn, request)
        except Exception as e:
            print("Request error:", e)
        finally:
            conn.close()


# ---------------------------------------------------------------------------
# Main
# ---------------------------------------------------------------------------
def main():
    try:
        wifi_connect()
        run_server()
    except Exception as e:
        # Any unhandled error -> make sure relays are safely OFF
        print("Fatal error, forcing relays OFF:", e)
        relays_off()
        # Optional: brief pause then reset so the device can retry
        time.sleep(5)
        machine.reset()


if __name__ == "__main__":
    main()

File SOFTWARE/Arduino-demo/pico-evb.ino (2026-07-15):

// ---------------------------------------------------------------
// Pin mapping
// ---------------------------------------------------------------
const uint8_t INPUT_PINS[4] = {2, 3, 8, 9};
const uint8_t RELAY_PINS[4] = {10, 11, 12, 13};

// Reserved peripheral pins per your wiring (not actively used here):
// UART:  TX=0, RX=1  (Serial uses these by default on most boards)
// I2C:   SDA=16(A2)? -- NOTE: on classic Arduino Uno/Nano these pin
//        numbers don't map directly to I2C; adjust for your actual
//        board (e.g. Pico via arduino-pico core, ESP32, etc.)
// SPI:   MISO=4, CS=5, SCK=6, MOSI=7

// ---------------------------------------------------------------
// Debounce timing
// ---------------------------------------------------------------
const unsigned long ON_DEBOUNCE_MS  = 5;
const unsigned long OFF_DEBOUNCE_MS = 60;

// ---------------------------------------------------------------
// Per-input state tracking
// ---------------------------------------------------------------
struct DebouncedInput {
  uint8_t pin;
  uint8_t relayPin;
  int lastReading;
  unsigned long changeTime;
};

DebouncedInput inputs[4];

// ---------------------------------------------------------------
// Force all relays OFF (fail-safe)
// ---------------------------------------------------------------
void relaysOff() {
  for (uint8_t i = 0; i < 4; i++) {
    digitalWrite(RELAY_PINS[i], LOW);
  }
}

void setup() {
  Serial.begin(9600);

  // Relays: set OFF *before* setting pinMode to OUTPUT where possible,
  // to avoid a brief undefined state on power-up.
  for (uint8_t i = 0; i < 4; i++) {
    digitalWrite(RELAY_PINS[i], LOW);
    pinMode(RELAY_PINS[i], OUTPUT);
    digitalWrite(RELAY_PINS[i], LOW); // redundant safety write
  }

  // Inputs: active-LOW, using internal pullups.
  // If your inputs idle LOW instead, switch to INPUT and invert logic.
  for (uint8_t i = 0; i < 4; i++) {
    pinMode(INPUT_PINS[i], INPUT_PULLUP);
    inputs[i].pin = INPUT_PINS[i];
    inputs[i].relayPin = RELAY_PINS[i];
    inputs[i].lastReading = digitalRead(INPUT_PINS[i]);
    inputs[i].changeTime = millis();
  }
}

void updateInput(DebouncedInput &di) {
  int reading = digitalRead(di.pin);
  unsigned long now = millis();

  if (reading != di.lastReading) {
    // Raw level changed - restart the timer for this new level
    di.lastReading = reading;
    di.changeTime = now;
    return;
  }

  unsigned long elapsed = now - di.changeTime;

  if (reading == LOW && elapsed >= ON_DEBOUNCE_MS) {
    digitalWrite(di.relayPin, HIGH);
  } else if (reading == HIGH && elapsed >= OFF_DEBOUNCE_MS) {
    digitalWrite(di.relayPin, LOW);
  }
}

void loop() {
  // Wrap the per-loop work so any unexpected condition can be
  // caught and relays forced off. (Arduino/C++ has no exceptions
  // enabled by default, so we rely on defensive checks instead —
  // see note below.)
  for (uint8_t i = 0; i < 4; i++) {
    updateInput(inputs[i]);
  }

  delay(1); // fine resolution needed for the 5ms ON threshold
}

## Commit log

2026-07-15 initial upload
    [PICO-EVB_Rev_A-B_Cu.gbr, PICO-EVB_Rev_A-B_Mask.gbr, PICO-EVB_Rev_A-B_Paste.gbr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]
2026-07-15 add Arduino code

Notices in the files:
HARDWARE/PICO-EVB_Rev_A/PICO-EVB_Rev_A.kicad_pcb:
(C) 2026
